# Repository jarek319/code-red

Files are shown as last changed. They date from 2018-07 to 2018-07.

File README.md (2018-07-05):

# code-red
A bunch of cool displays thrown together

I was digging through my pile of spare parts and found a few displays I wanted to get up and running.

The simple board just arranges them all in a pleasing way. I have had some success getting them through their entire character set, but need to think about how to serialize the data for all these different devices...

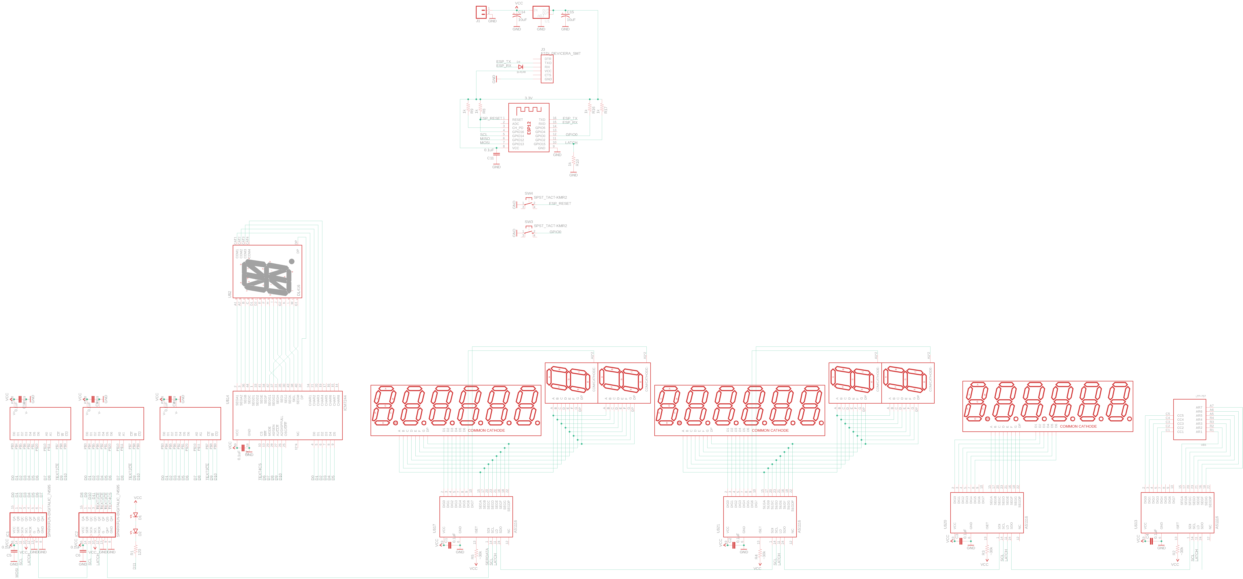
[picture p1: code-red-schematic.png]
schematic

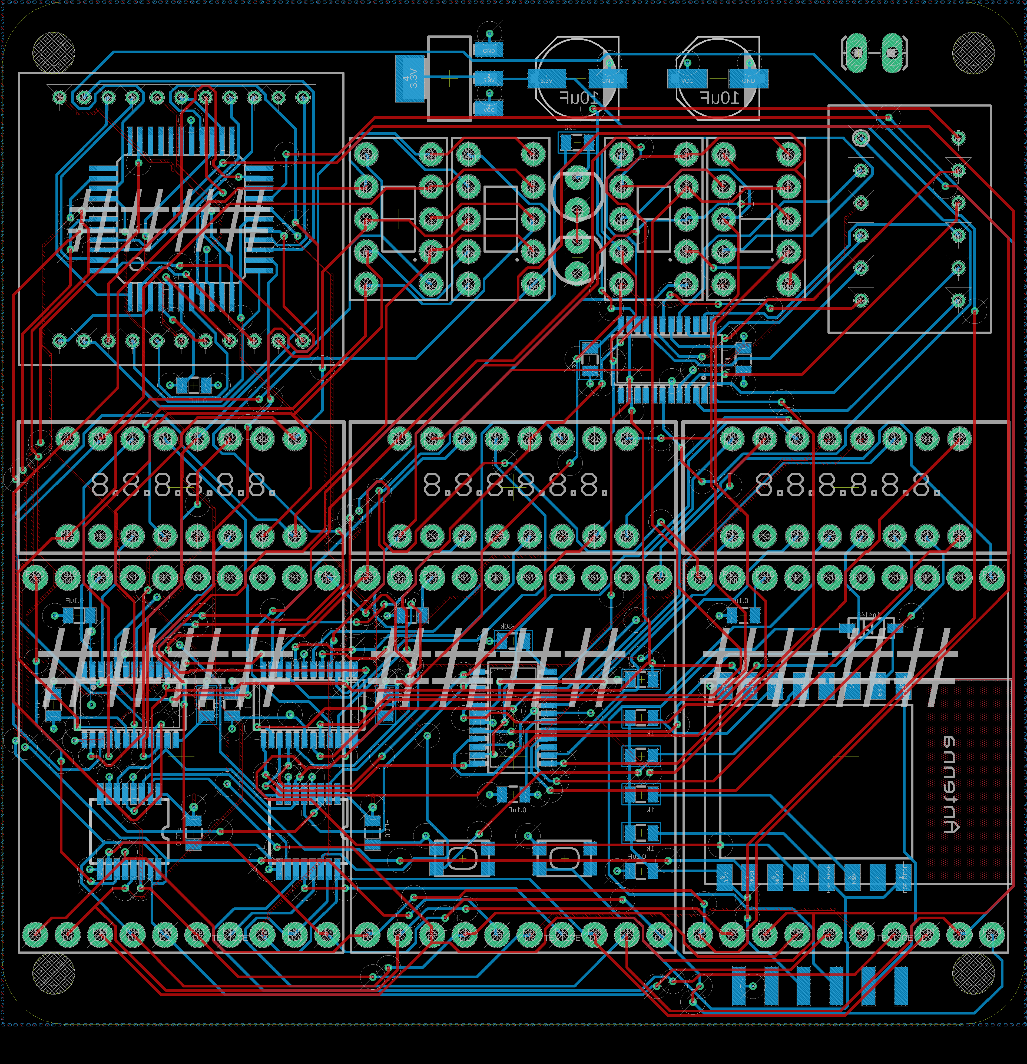
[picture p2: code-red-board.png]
board


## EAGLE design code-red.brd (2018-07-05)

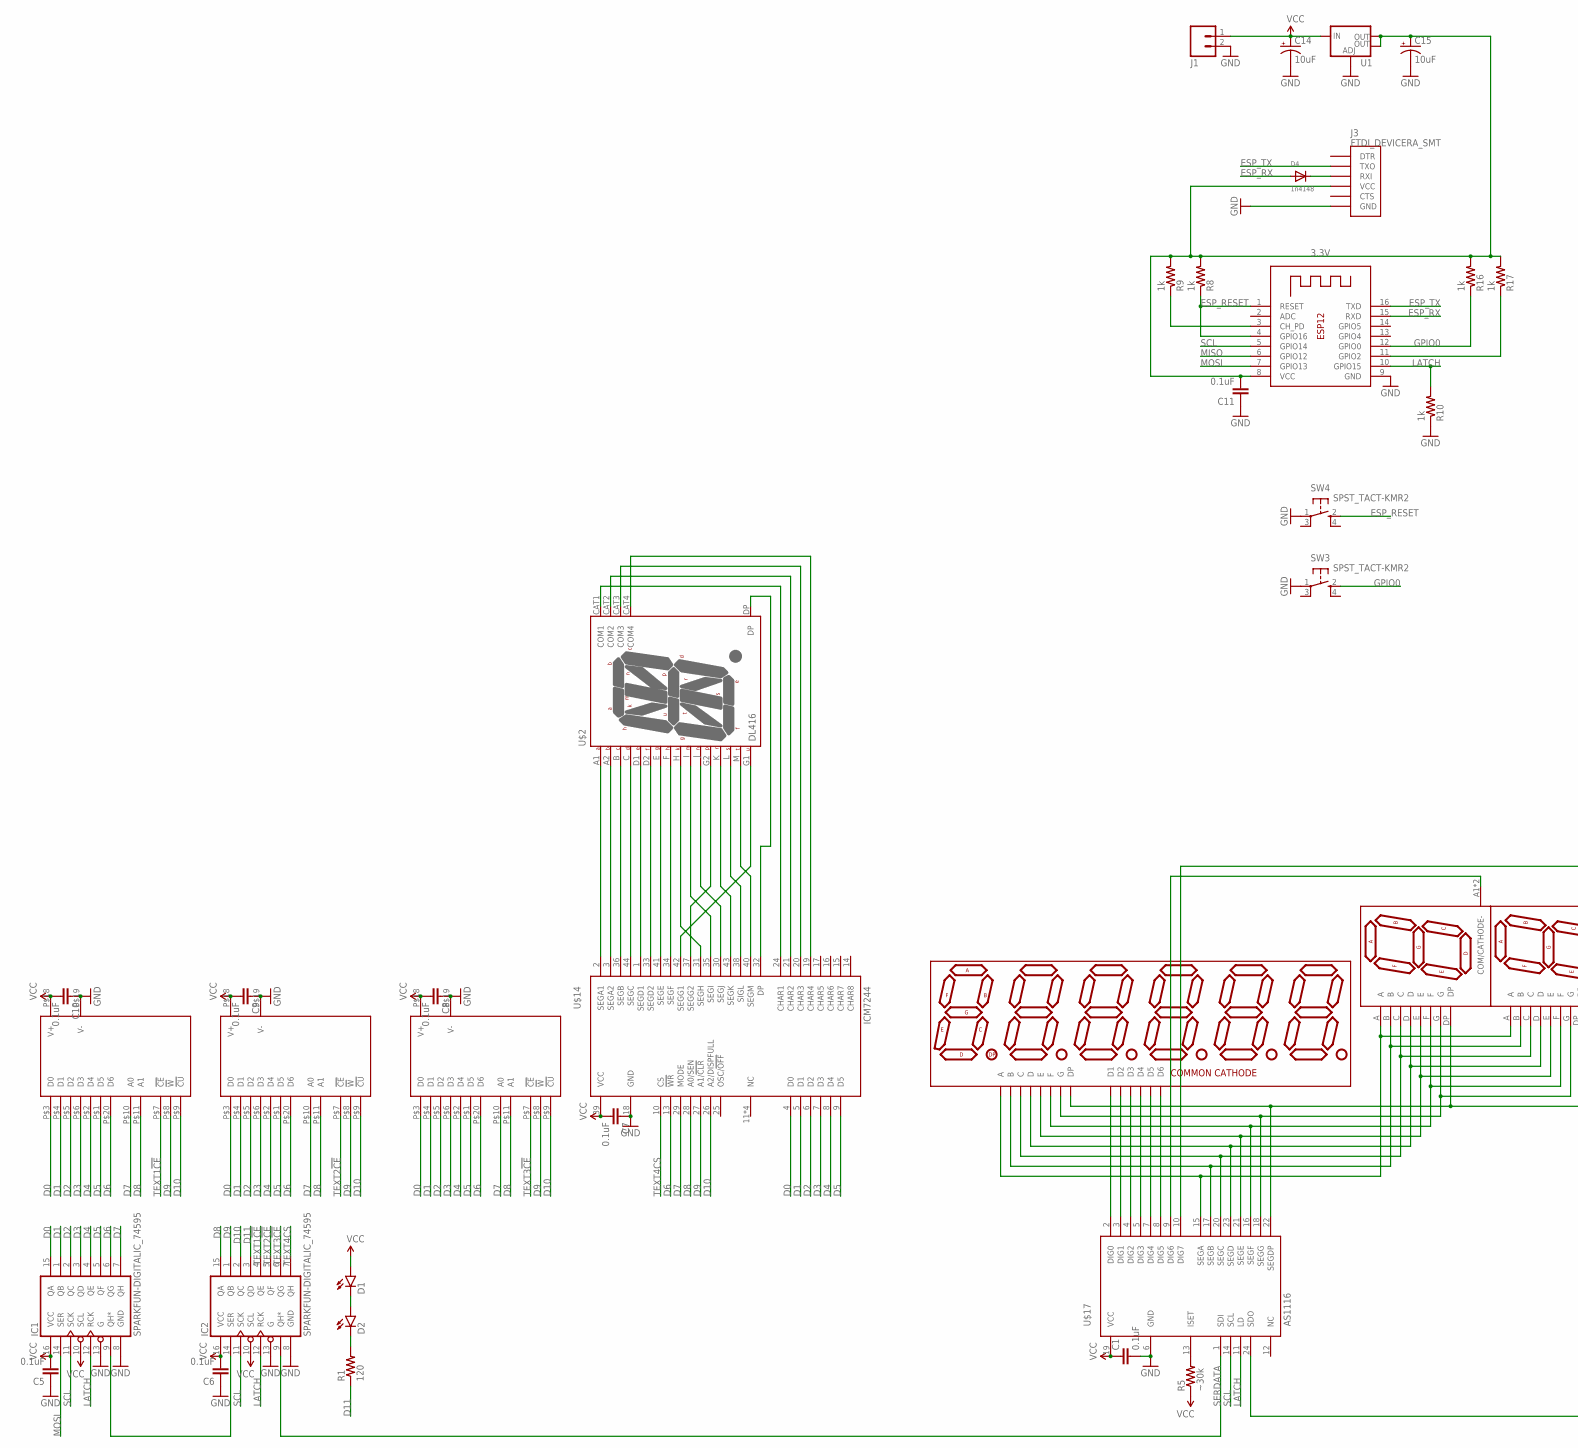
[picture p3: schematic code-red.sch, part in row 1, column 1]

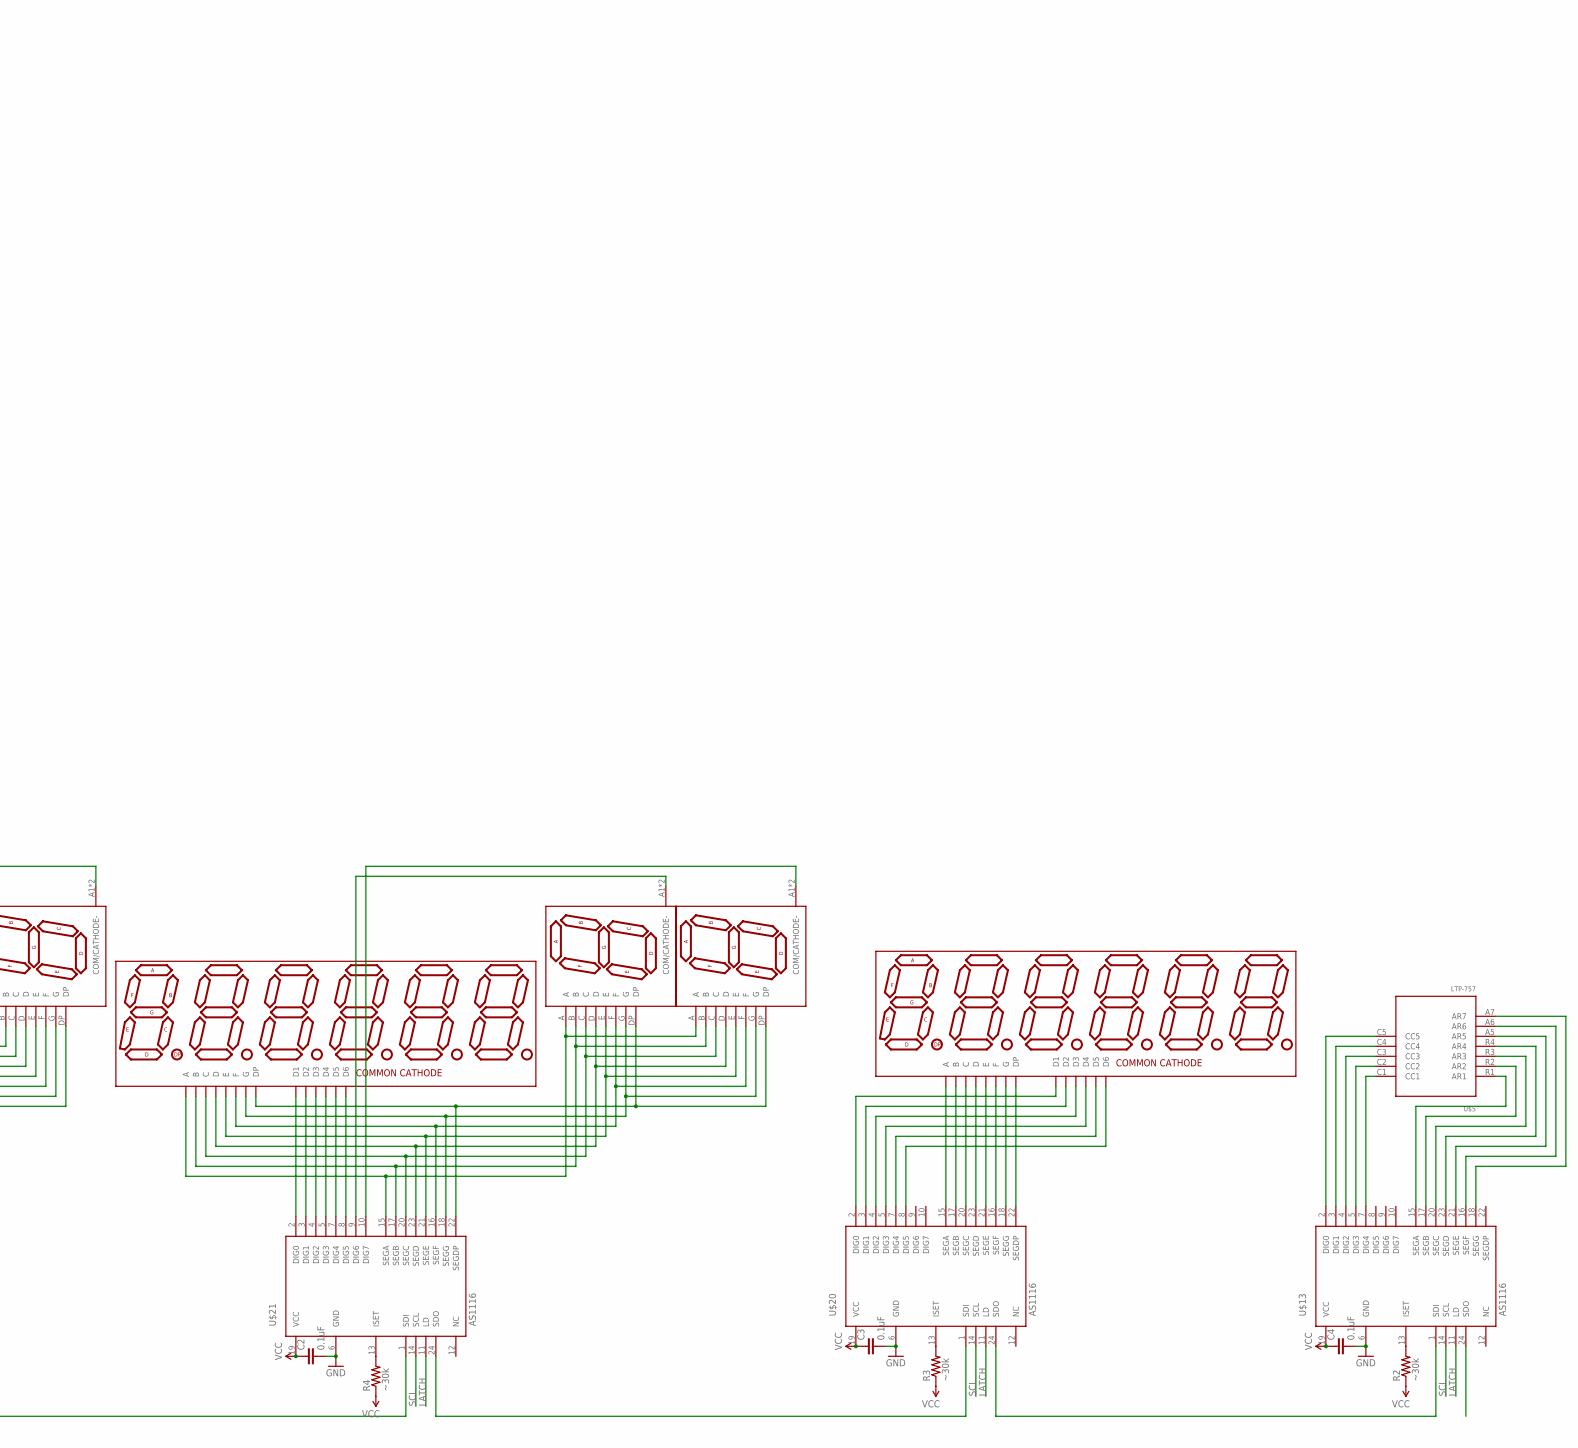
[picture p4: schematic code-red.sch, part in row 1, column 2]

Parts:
C1, C2, C3, C4, C5, C6, C7, C8, C9, C10, C11: 0.1uF; 0805
C14, C15: 10uF; PANASONIC_D
D1, D2: LED3MM
D4: 1n4148; SOD-123
IC1, IC2: SPARKFUN-DIGITALIC_74595; SPARKFUN-DIGITALIC_TSSOP16
J1: M02LOCK_LONGPADS; 1X02_LOCK_LONGPADS
J3: FTDI_DEVICERA_SMT; FTDI_DEVICE_RA_SMT
R1: 120; 0805
R2, R3, R4, R5: ~30k; 0805
R8, R9, R10, R16, R17: 1k; 0805
SW3, SW4: SPST_TACT-KMR2; KMR2
U1: V_REG_LM1117SOT223; SOT223
U$1, U$6, U$7: DIS1291
U$2: DL416
U$3, U$8, U$9: DL1416T
U$4, U$10, U$11, U$12: FND259; FND359
U$5: LTP-757
U$13, U$17, U$20, U$21: AS1116; SSOP24
U$14: ICM7244; MQFP44-2
X1: ESP-12

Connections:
3.3V: C11.2, C15.+, J3.4 (VCC), R8.2, R9.2, R16.2, R17.2, U1.2 (OUT), U1.4 (OUT), X1.8 (VCC)
D0: IC1.15 (QA), U$3.P$3 (D0), U$8.P$3 (D0), U$9.P$3 (D0), U$14.4 (D0)
D1: IC1.1 (QB), U$3.P$4 (D1), U$8.P$4 (D1), U$9.P$4 (D1), U$14.5 (D1)
D2: IC1.2 (QC), U$3.P$5 (D2), U$8.P$5 (D2), U$9.P$5 (D2), U$14.6 (D2)
D3: IC1.3 (QD), U$3.P$6 (D3), U$8.P$6 (D3), U$9.P$6 (D3), U$14.7 (D3)
D4: IC1.4 (QE), U$3.P$2 (D4), U$8.P$2 (D4), U$9.P$2 (D4), U$14.8 (D4)
D5: IC1.5 (QF), U$3.P$1 (D5), U$8.P$1 (D5), U$9.P$1 (D5), U$14.9 (D5)
D6: IC1.6 (QG), U$3.P$20 (D6), U$8.P$20 (D6), U$9.P$20 (D6), U$14.13 (!WR)
D7: IC1.7 (QH), U$3.P$10 (A0), U$8.P$10 (A0), U$9.P$10 (A0), U$14.29 (MODE)
D8: IC2.15 (QA), U$3.P$11 (A1), U$8.P$11 (A1), U$9.P$11 (A1), U$14.28 (A0/SEN)
D9: IC2.1 (QB), U$3.P$8 (!W), U$8.P$8 (!W), U$9.P$8 (!W), U$14.27 (A1/!CLR)
D10: IC2.2 (QC), U$3.P$9 (!CU), U$8.P$9 (!CU), U$9.P$9 (!CU), U$14.26 (A2/DISPFULL)
D11: IC2.3 (QD), R1.1
ESP_RESET: R8.1, SW4.2 (S), X1.1 (RESET), X1.4 (GPIO16)
ESP_RX: D4.A, X1.15 (RXD)
ESP_TX: J3.2 (TXO), X1.16 (TXD)
GND: C1.2, C2.2, C3.2, C4.2, C5.1, C6.1, C7.1, C8.1, C9.1, C10.1, C11.1, C14.-, C15.-, IC1.8 (GND), IC1.13 (G), IC2.8 (GND), IC2.13 (G), J1.2, J3.6 (GND), R10.1, SW3.1, SW4.1, U1.1 (ADJ), U$3.P$19 (V-), U$8.P$19 (V-), U$9.P$19 (V-), U$13.6 (GND), U$14.18 (GND), U$17.6 (GND), U$20.6 (GND), U$21.6 (GND), X1.9 (GND)
GPIO0: R16.1, SW3.2 (S), X1.12 (GPIO0)
LATCH: IC1.12 (RCK), IC2.12 (RCK), R10.2, U$13.11 (LD), U$17.11 (LD), U$20.11 (LD), U$21.11 (LD), X1.10 (GPIO15)
MISO: X1.6 (GPIO12)
MOSI: IC1.14 (SER), X1.7 (GPIO13)
unnamed: U$1.P$12 (A), U$4.A, U$10.A, U$17.15 (SEGA)
unnamed: U$1.P$16 (F), U$4.F, U$10.F, U$17.16 (SEGF)
unnamed: U$1.P$15 (B), U$4.B, U$10.B, U$17.17 (SEGB)
unnamed: U$1.P$9 (G), U$4.G, U$10.G, U$17.18 (SEGG)
unnamed: U$1.P$1 (C), U$4.C, U$10.C, U$17.20 (SEGC)
unnamed: U$1.P$7 (E), U$4.E, U$10.E, U$17.21 (SEGE)
unnamed: U$1.P$8 (DP), U$4.DP, U$10.DP, U$17.22 (SEGDP)
unnamed: U$1.P$4 (D), U$4.D, U$10.D, U$17.23 (SEGD)
unnamed: U$1.P$14 (D1), U$17.2 (DIG0)
unnamed: U$1.P$3 (D2), U$17.3 (DIG1)
unnamed: U$1.P$13 (D3), U$17.4 (DIG2)
unnamed: U$1.P$5 (D4), U$17.5 (DIG3)
unnamed: U$1.P$11 (D5), U$17.7 (DIG4)
unnamed: U$1.P$6 (D6), U$17.8 (DIG5)
unnamed: U$6.P$12 (A), U$11.A, U$12.A, U$21.15 (SEGA)
unnamed: U$6.P$16 (F), U$11.F, U$12.F, U$21.16 (SEGF)
unnamed: U$6.P$15 (B), U$11.B, U$12.B, U$21.17 (SEGB)
unnamed: U$6.P$9 (G), U$11.G, U$12.G, U$21.18 (SEGG)
unnamed: U$6.P$1 (C), U$11.C, U$12.C, U$21.20 (SEGC)
unnamed: U$6.P$7 (E), U$11.E, U$12.E, U$21.21 (SEGE)
unnamed: U$6.P$8 (DP), U$11.DP, U$12.DP, U$21.22 (SEGDP)
unnamed: U$6.P$4 (D), U$11.D, U$12.D, U$21.23 (SEGD)
unnamed: U$6.P$14 (D1), U$21.2 (DIG0)
unnamed: U$6.P$3 (D2), U$21.3 (DIG1)
unnamed: U$6.P$13 (D3), U$21.4 (DIG2)
unnamed: U$6.P$5 (D4), U$21.5 (DIG3)
unnamed: U$6.P$11 (D5), U$21.7 (DIG4)
unnamed: U$6.P$6 (D6), U$21.8 (DIG5)
unnamed: U$7.P$12 (A), U$20.15 (SEGA)
unnamed: U$7.P$16 (F), U$20.16 (SEGF)
unnamed: U$7.P$15 (B), U$20.17 (SEGB)
unnamed: U$7.P$9 (G), U$20.18 (SEGG)
unnamed: U$7.P$1 (C), U$20.20 (SEGC)
unnamed: U$7.P$7 (E), U$20.21 (SEGE)
unnamed: U$7.P$8 (DP), U$20.22 (SEGDP)
unnamed: U$7.P$4 (D), U$20.23 (SEGD)
unnamed: U$7.P$14 (D1), U$20.2 (DIG0)
unnamed: U$7.P$3 (D2), U$20.3 (DIG1)
unnamed: U$7.P$13 (D3), U$20.4 (DIG2)
unnamed: U$7.P$5 (D4), U$20.5 (DIG3)
unnamed: U$7.P$11 (D5), U$20.7 (DIG4)
unnamed: U$7.P$6 (D6), U$20.8 (DIG5)
unnamed: U$2.G1 (U), U$14.42 (SEGG1)
unnamed: R2.2, U$13.13 (ISET)
unnamed: R3.2, U$20.13 (ISET)
unnamed: R4.2, U$21.13 (ISET)
unnamed: R5.2, U$17.13 (ISET)
unnamed: IC1.9 (QH*), IC2.14 (SER)
unnamed: U$2.CAT1 (COM1), U$14.24 (CHAR1)
unnamed: U$13.1 (SDI), U$20.24 (SDO)
unnamed: D1.K (C), D2.A
unnamed: D2.K (C), R1.2
unnamed: U$2.A1 (A), U$14.2 (SEGA1)
unnamed: U$5.C1 (CC1), U$13.7 (DIG4)
unnamed: U$5.C2 (CC2), U$13.5 (DIG3)
unnamed: U$5.C3 (CC3), U$13.4 (DIG2)
unnamed: U$5.C4 (CC4), U$13.3 (DIG1)
unnamed: U$5.C5 (CC5), U$13.2 (DIG0)
unnamed: U$5.R1 (AR1), U$13.15 (SEGA)
unnamed: U$5.R2 (AR2), U$13.17 (SEGB)
unnamed: U$5.R3 (AR3), U$13.20 (SEGC)
unnamed: U$5.R4 (AR4), U$13.23 (SEGD)
unnamed: U$5.A5 (AR5), U$13.21 (SEGE)
unnamed: U$5.A6 (AR6), U$13.16 (SEGF)
unnamed: U$5.A7 (AR7), U$13.18 (SEGG)
unnamed: U$2.B (C1), U$14.36 (SEGB)
unnamed: U$2.C (D), U$14.44 (SEGC)
unnamed: U$20.1 (SDI), U$21.24 (SDO)
unnamed: U$2.CAT2 (COM2), U$14.21 (CHAR2)
unnamed: U$2.CAT3 (COM3), U$14.20 (CHAR3)
unnamed: U$2.CAT4 (COM4), U$14.19 (CHAR4)
unnamed: U$17.24 (SDO), U$21.1 (SDI)
unnamed: U$2.A2 (B1), U$14.3 (SEGA2)
unnamed: U$2.D2 (F1), U$14.33 (SEGD2)
unnamed: U$2.E (G), U$14.41 (SEGE)
unnamed: U$2.F (H1), U$14.34 (SEGF)
unnamed: U$2.H (K1), U$14.31 (SEGH)
unnamed: U$2.I (M1), U$14.35 (SEGI)
unnamed: U$2.J (N), U$14.30 (SEGJ)
unnamed: U$2.K (R), U$14.43 (SEGK)
unnamed: U$2.L (S), U$14.38 (SIGL)
unnamed: U$2.M (T), U$14.40 (SEGM)
unnamed: U$2.D1 (E1), U$14.1 (SEGD1)
unnamed: U$2.DP, U$14.32 (DP)
unnamed: U$2.G2, U$14.37 (SEGG2)
unnamed: U$4.A1 (COM/CATHODE-), U$4.A2 (COM/CATHODE-), U$17.9 (DIG6)
unnamed: U$10.A1 (COM/CATHODE-), U$10.A2 (COM/CATHODE-), U$17.10 (DIG7)
unnamed: U$11.A1 (COM/CATHODE-), U$11.A2 (COM/CATHODE-), U$21.9 (DIG6)
unnamed: U$12.A1 (COM/CATHODE-), U$12.A2 (COM/CATHODE-), U$21.10 (DIG7)
unnamed: R9.1, X1.3 (CH_PD)
unnamed: D4.C, J3.3 (RXI)
unnamed: R17.1, X1.11 (GPIO2)
SCL: IC1.11 (SCK), IC2.11 (SCK), U$13.14 (SCL), U$17.14 (SCL), U$20.14 (SCL), U$21.14 (SCL), X1.5 (GPIO14)
SERDATA: IC2.9 (QH*), U$17.1 (SDI)
TEXT1!CE: IC2.4 (QE), U$3.P$7 (!CE)
TEXT2!CE: IC2.5 (QF), U$8.P$7 (!CE)
TEXT3!CE: IC2.6 (QG), U$9.P$7 (!CE)
TEXT4CS: IC2.7 (QH), U$14.10 (CS)
VCC: C1.1, C2.1, C3.1, C4.1, C5.2, C6.2, C7.2, C8.2, C9.2, C10.2, C14.+, D1.A, IC1.10 (SCL), IC1.16 (VCC), IC2.10 (SCL), IC2.16 (VCC), J1.1, R2.1, R3.1, R4.1, R5.1, U1.3 (IN), U$3.P$18 (V+), U$8.P$18 (V+), U$9.P$18 (V+), U$13.19 (VCC), U$14.39 (VCC), U$17.19 (VCC), U$20.19 (VCC), U$21.19 (VCC)

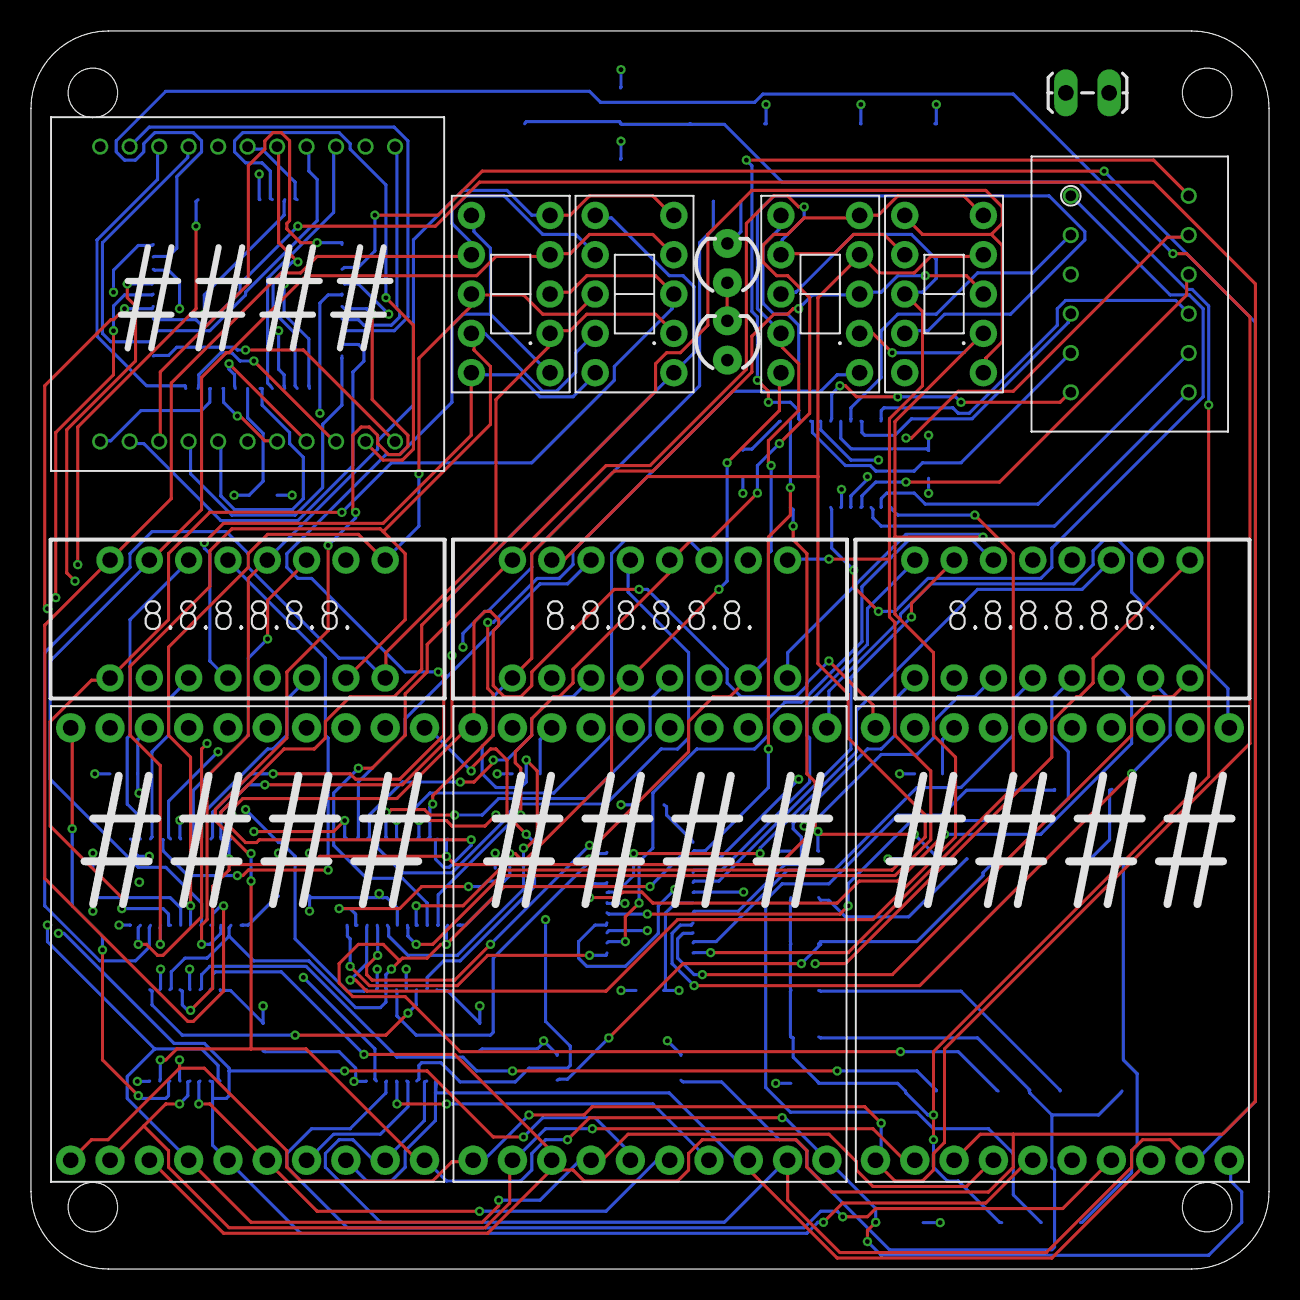
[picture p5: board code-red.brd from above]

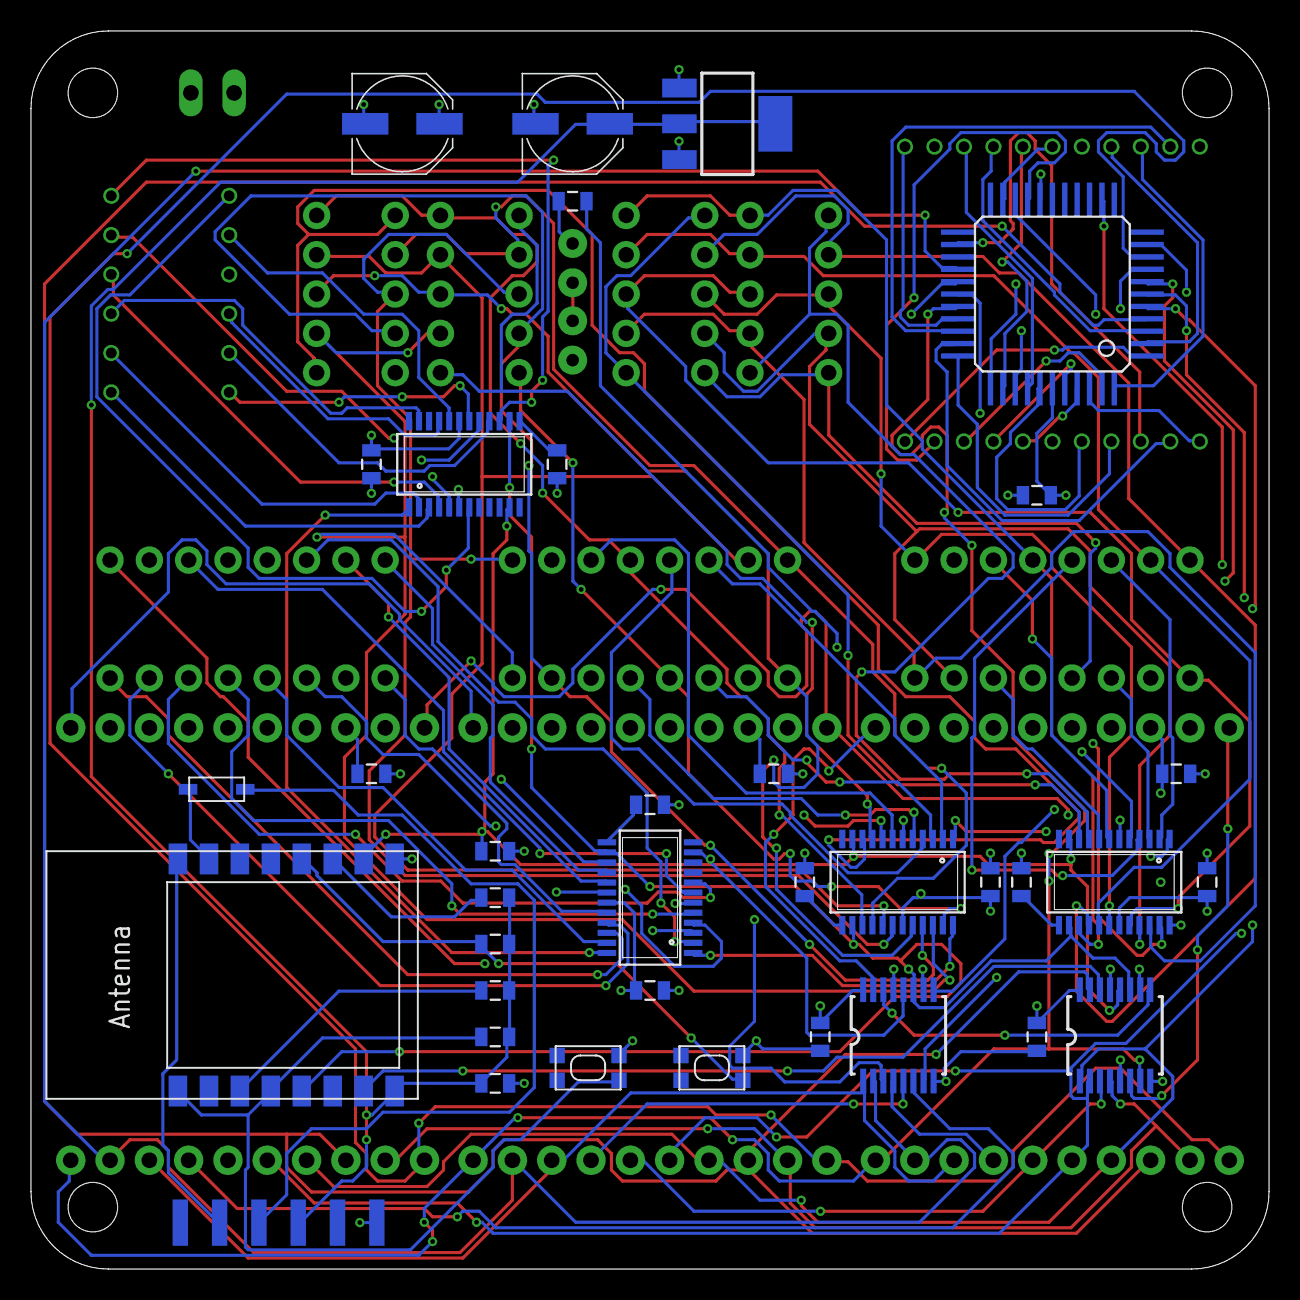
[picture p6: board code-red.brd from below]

Board: 4 copper layers, 80.0 x 80.0 mm, 51 parts (36 on the bottom side), 119 nets.

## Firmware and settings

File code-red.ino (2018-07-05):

#include <SPI.h>
#define LATCH 15

//595: !TEXT4CS !TEXT3CS !TEXT2CS !TEXT1CS !D11 D10 D9 D8 D7 D6 D5 D4 D3 D2 D1 D0
#define SR_A0  ( 1 << 7 )
#define SR_A1  ( 1 << 8 )
#define SR_W   ( 1 << 9 )
#define SR_CU  ( 1 << 10 )
#define SR_CLN ( 1 << 11 ) // LOW is on
#define SR_CE1 ( 1 << 12 )
#define SR_CE2 ( 1 << 13 )
#define SR_CE3 ( 1 << 14 )
#define SR_CE4 ( 1 << 15 )
#define ICM_A0 ( 1 << 8 )
#define ICM_A1 ( 1 << 9 )
#define ICM_A2 ( 1 << 10 )
#define ICM_MODE ( 1 << 7 )
#define ICM_W ( 1 << 6 )

//DL1416T: X X X X X !CU !W A1 A0 D6 D5 D4 D3 D2 D1 D0

//ICM7244: X X X X X A2 A1 A0 MODE !WR D5 D4 D2 D2 D1 D0
//COLONS: !D11

//AS1116: X R/W 0 REG5 REG4 REG3 REG2 REG1 REG0 D7 D6 D5 D4 D3 D2 D1 D0
#define AS_NOP    0x0000
#define AS_DIGIT0 0x0100
#define AS_DIGIT1 0x0200
#define AS_DIGIT2 0x0300
#define AS_DIGIT3 0x0400
#define AS_DIGIT4 0x0500
#define AS_DIGIT5 0x0600
#define AS_DIGIT6 0x0700
#define AS_DIGIT7 0x0800
#define AS_DECODE 0x0900
#define AS_GINTEN 0x0A00
#define AS_SCNLIM 0X0B00
#define AS_SHTDWN 0x0C00
#define AS_FEATUR 0x0E00
#define AS_TSTMDE 0x0F00
#define AS_D01ITY 0x1000
#define AS_D23ITY 0x1100
#define AS_D45ITY 0x1200
#define AS_D67ITY 0x1300
// First three displays are DL1416T and 4th is ICM7244
// ICM7244 controls the top left 4 digit 16 seg display
// These four are accessed using two shift registers
// The 595 shift registers map to the chip inputs as per above
// Four AS1116 displays follow the shift registers
// AS1116-4 is the dot matrix
// AS1116-3 is the rightmost red 7seg cluster
// AS1116-2 is the middle red 7seg cluster and right two digits next to colon
// AS1116-1 is the left red 7seg cluster and left two digits next to colon
// So the order should be
// AS1116-4 AS1116-3 AS1116-2 AS1116-1 595-2 595-1


uint16_t sr = 0x0000;
uint16_t as1 = 0x0C01;
uint16_t as2 = 0x0C01;
uint16_t as3 = 0x0C01;
uint16_t as4 = 0x0C01;

uint8_t Bit_Reverse( uint8_t x ) 
{ 
   x = ((x >> 1) & 0x55) | ((x << 1) & 0xaa); 
   x = ((x >> 2) & 0x33) | ((x << 2) & 0xcc); 
   x = ((x >> 4) & 0x0f) | ((x << 4) & 0xf0); 
   return x;    
}

void updateDisplays() {
  digitalWrite( LATCH, LOW );
  //as4 = ( Bit_Reverse( as4 & 0xFF ) ) | ( Bit_Reverse(( as4 >> 4 ) & 0xFF ));
  SPI.transfer16( as4 );
  SPI.transfer16( as3 );
  SPI.transfer16( as2 );
  SPI.transfer16( as1 );
  SPI.transfer16( sr );
  digitalWrite( LATCH, HIGH );
  digitalWrite( LATCH, LOW );
  SPI.transfer16( as4 );
  SPI.transfer16( as3 );
  SPI.transfer16( as2 );
  SPI.transfer16( as1 );
  SPI.transfer16(( sr | SR_CE1 | SR_CE2 | SR_CE3 | ICM_W ) & ~(SR_CE4) );
  digitalWrite( LATCH, HIGH );
}

void setup() {
  Serial.begin( 115200 );
  Serial.println( "hi" );
  SPI.begin();
  pinMode( LATCH, OUTPUT );
  digitalWrite( LATCH, LOW );
  //AS1116 send 0x01 to AS_SHTDWN
  as4 = AS_SHTDWN | 0x01;
  as3 = AS_SHTDWN | 0x01;
  as2 = AS_SHTDWN | 0x01;
  as1 = AS_SHTDWN | 0x01;
  updateDisplays();
  as4 = AS_GINTEN | 0xFF;
  as3 = AS_GINTEN | 0xFF;
  as2 = AS_GINTEN | 0xFF;
  as1 = AS_GINTEN | 0xFF;
  updateDisplays();
  as4 = AS_SCNLIM | 0x07;
  as3 = AS_SCNLIM | 0x07;
  as2 = AS_SCNLIM | 0x07;
  as1 = AS_SCNLIM | 0x07;
  updateDisplays();
}

void loop() {
  for ( uint16_t i = 0; i < 0xFF; i++ ) {
    Serial.println( i, HEX );
    as1 = AS_DIGIT0 | i;
    as2 = AS_DIGIT2 | i;
    as3 = AS_DIGIT5 | i;
    as4 = AS_DIGIT7 | i;
    
    sr = SR_CE1 | SR_CE2 | SR_CU | 'L' ;
    updateDisplays();
    sr = SR_CE1 | SR_CE2 | SR_CU | SR_A0 | 'I' ;
    updateDisplays();
    sr = SR_CE1 | SR_CE2 | SR_CU | SR_A1 | 'A' ;
    updateDisplays();
    sr = SR_CE1 | SR_CE2 | SR_CU | SR_A0 | SR_A1 | 'M' ;
    updateDisplays();
    sr = SR_CE1 | SR_CE3 | SR_CU | 'W' ;
    updateDisplays();
    sr = SR_CE1 | SR_CE3 | SR_CU | SR_A0 | 'O' ;
    updateDisplays();
    sr = SR_CE1 | SR_CE3 | SR_CU | SR_A1 | 'L' ;
    updateDisplays();
    sr = SR_CE1 | SR_CE3 | SR_CU | SR_A0 | SR_A1 | ( i & 0x3F ) ;
    updateDisplays();
    sr = SR_CE2 | SR_CE3 | SR_CU | 'H' ;
    updateDisplays();
    sr = SR_CE2 | SR_CE3 | SR_CU | SR_A0 | 'G' ;
    updateDisplays();
    sr = SR_CE2 | SR_CE3 | SR_CU | SR_A1 | 'I' ;
    updateDisplays();
    sr = SR_CE2 | SR_CE3 | SR_CU | SR_A0 | SR_A1 | 'H' ;
    updateDisplays();
    sr = ( SR_CE1 | SR_CE2 | SR_CE3 | SR_CE4 | 'T' ) & ~( ICM_W );
    updateDisplays();
    sr = ( SR_CE1 | SR_CE2 | SR_CE3 | SR_CE4 | ICM_A0 | 'I' ) & ~( ICM_W );
    updateDisplays();
    sr = ( SR_CE1 | SR_CE2 | SR_CE3 | SR_CE4 | ICM_A1 | 'M' ) & ~( ICM_W );
    updateDisplays();
    sr = ( SR_CE1 | SR_CE2 | SR_CE3 | SR_CE4 | ICM_A0 | ICM_A1 | 'E' ) & ~( ICM_W );
    updateDisplays();
    delay( 25 );
  }
}

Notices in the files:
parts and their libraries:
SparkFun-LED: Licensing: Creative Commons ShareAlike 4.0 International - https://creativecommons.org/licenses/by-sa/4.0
